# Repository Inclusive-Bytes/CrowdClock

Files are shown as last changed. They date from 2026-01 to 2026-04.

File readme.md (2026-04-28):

# CrowdClock

**Self-synchronising LED badges using ESP-NOW**

> A distributed system where devices don’t sync animations — they sync time.

---

## 🎥 Demo

See the badges in action:
👉 [https://youtu.be/YINVdLlnf9U(https://youtu.be/YINVdLlnf9U)

Badges automatically synchronise their lighting effects when they come close together.

* No pairing
* No configuration
* No central controller

They just… sync.

---

## 🧠 How It Works

Each badge broadcasts its local clock using ESP-NOW.
Instead of sending raw time, the value is **quantised into 50 ms steps**:

```cpp
tick = millis() - (millis() % 50);
```

When a badge receives a time value greater than its own, it adopts it:

```cpp
time = max(time_seen);
```

This creates a simple, emergent synchronisation mechanism:

* No master node
* No topology
* No device tracking

---

## 🔄 From Time to Light

All badges run the same code and derive their behaviour from time:

```
tick → effect index → effect state → LED output
```

* **Effect selection** is based on time
* **Effect state** is based on time

Once clocks align, everything else follows automatically.

---

## ⚙️ Why It Works

### 🔹 Quantised Time

Rounding time to 50 ms:

* Absorbs network latency
* Prevents oscillation
* Ensures stable convergence

### 🔹 Fast Broadcast

* ESP-NOW transmission every ~5 ms
* Multiple opportunities for propagation

### 🔹 Perceptual Design

Effects are:

* Flashes
* Chases
* Discrete patterns

This avoids visible artefacts from small timing differences.

---

## 🧩 Hardware

Each badge includes:

* ESP32-C3 Mini
* WS2812 LED ring
* 1Ah LiPo battery
* Boost/BMS module (5V output)

PCBs were CNC routed and assembled in workshops.

---

## 🔧 A Note on ESP32 Mounting

Early versions used socketed ESP32 modules.
This caused unreliable ESP-NOW reception.

Removing the sockets and soldering the modules directly resolved the issue.

At 2.4 GHz, small physical details matter.

---

## 👩‍🔧 Built with Inclusive Bytes

This project was developed with participants at
Inclusive Bytes

* Community workshops
* Soldering and assembly
* Custom lighting effects written by students

The system itself mirrors the process:

> many independent parts working together to create something unified.

---

## 🎉 In the Wild

The badges were created for the Oldham Illuminate Festival.

* Small groups synchronise
* Groups merge and re-align
* The crowd becomes part of the system

---

## 🚀 Future Ideas

* Visualising time propagation
* Multiple competing “time groups”
* Alternative effect systems
* Binary packet format (non-JSON)

---

## 📦 Repository Structure

https://github.com/Inclusive-Bytes/CrowdClock

```
/src            → firmware  
/include 		→ header files
/hardware       → PCB and design files  

```

---

## 📜 Licence

This project is released under a Creative Commons licence  CC BY-NC 4.0

You are free to:

* Share
* Adapt
* Build upon

Please provide appropriate credit.

---

## 💡 Key Idea

> Synchronise time, not state.

---

## 🙌 Acknowledgements

Thanks to everyone at Inclusive Bytes who helped build, test, and extend the badges.

---

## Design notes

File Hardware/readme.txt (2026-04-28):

All these files are produced with the free electronic cad package DesignSpark
https://uk.rs-online.com/web/content/services/manufacturing-design/rs-design-spark

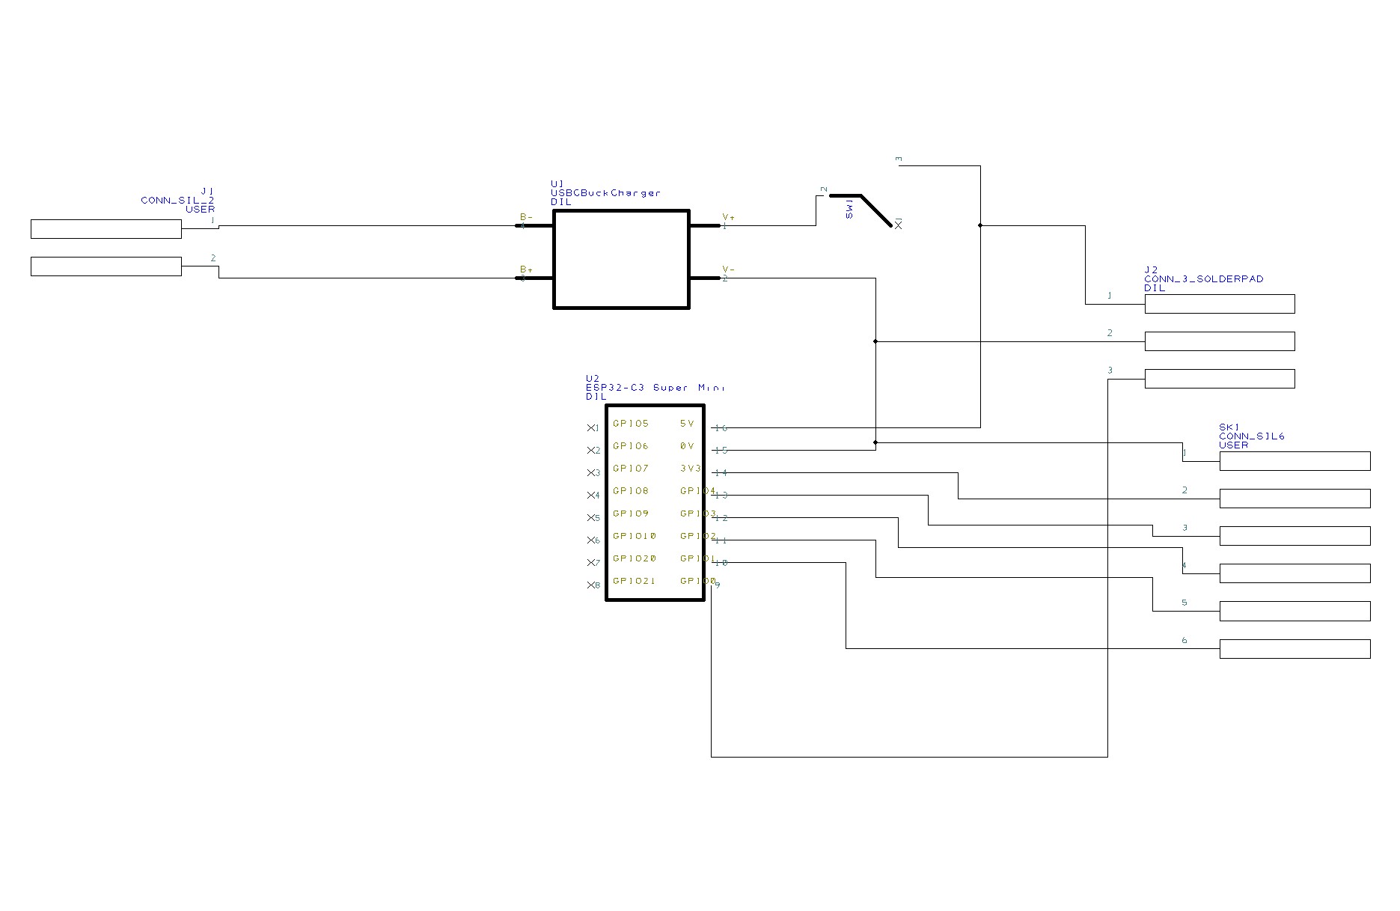
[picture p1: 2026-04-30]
Hardware/Schematic.jpg

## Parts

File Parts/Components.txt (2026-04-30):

Battery charger step up : https://www.aliexpress.com/item/1005005656423941.html
ESP32 C3: https://www.aliexpress.com/item/1005010195000050.html
WS2812 Ring. 16 LEDs: https://www.aliexpress.com/item/1005002304069758.html 
LipoBattery: https://www.aliexpress.com/item/1005010587681795.html
Slide switch: https://www.aliexpress.com/item/32797917204.html
Molex KK 2 way housing  254 : https://cpc.farnell.com/molex/10-11-2023/connector-rcpt-2pos-1row-2-54mm/dp/CN25601
Molex KK 2 way header 254: https://cpc.farnell.com/molex/22-27-2021/pin-header-0-1-2-way-lock/dp/CN09578
Molex KK crimps 254 x 2: https://cpc.farnell.com/molex/08-50-0113/contact-socket-22awg-crimp/dp/CN25571

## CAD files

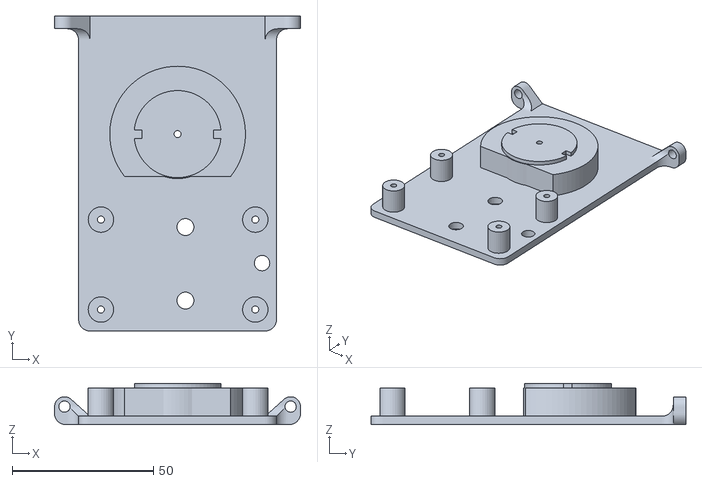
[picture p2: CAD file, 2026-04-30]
Parts/BadgeMount.stl
87.0 x 111.4 x 14.7

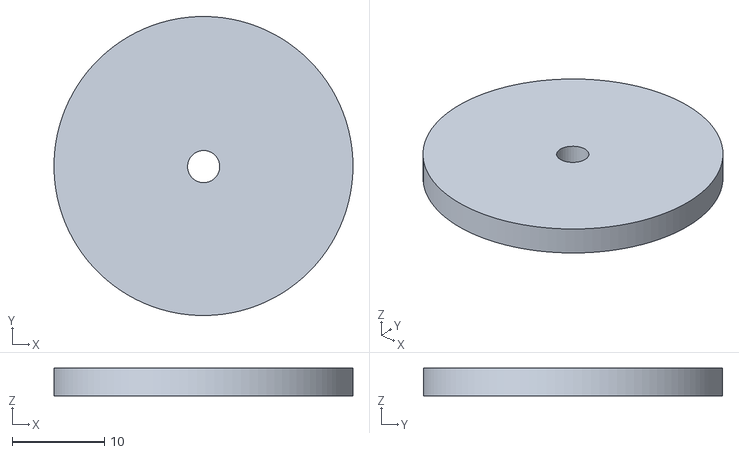
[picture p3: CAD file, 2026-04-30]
Parts/NeopixelClampRing.stl
32.5 x 32.5 x 3.00

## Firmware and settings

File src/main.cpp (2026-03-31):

/**
 * @file
 *
 * EspNowBroadcast.ino demonstrates how to perform ESP-NOW pseudo broadcast with @c WifiEspNowBroadcast .
 * You need two or more ESP8266 or ESP32 devices to run this example.
 *
 * All devices should run the same program.
 * You may need to modify the PIN numbers so that you can observe the effect.
 *
 * With the program running on several devices:
 * @li Press the button to transmit a message.
 * @li When a device receives a message, it will toggle its LED between "on" and "off" states.
 */

#include <WifiEspNowBroadcast.h>
#include "FastLED.h"
#if defined(ARDUINO_ARCH_ESP8266)
#include <ESP8266WiFi.h>
#elif defined(ARDUINO_ARCH_ESP32)
#include <WiFi.h>
#endif
#include "PacerLED.h"
#include "TxTime.h"
#include "JSONTime.h"
#include "TimeFilter.h"
#include "EffectManager.h"
#include "EffectStepColour.h"
#include "GenericFlasher.h"
#include "Ports.h"
#include "ContextStatusLed.h"
#include "EffectSwipe.h"
#include "EffectSynchronisedFlash.h"
#include "EffectHorizontalPath.h"
#include "EffectSpiral.h"
#include "EffectOrbit.h"
#include "EffectTriOrbit.h"


#define NUM_PIXELS 16

CRGB strip[NUM_PIXELS];



TxTime txTime(5, 5);  // Tx every 5ms scaled to 5ms

ContextStatusLed statusLED(STATUS_LED);

JSONTime jsonTime;
SystemTime systemTime;
TimeFilter timeFilter(&systemTime, 5);  // See if a new time received every 5ms

EffectManager effectManager;


GenericFlasher effectPurpleChase(CRGB(80,0,80), NUM_PIXELS);
GenericFlasher effectGreenChase(CRGB(0,128,0), NUM_PIXELS);
SwipeEffect   effectSwipe(CRGB(0,40,80), NUM_PIXELS);
SwipeEffect   effectSwipeRed(CRGB(200,0,0), NUM_PIXELS);
EffectSynchronisedFlash effectSyncFlash(NUM_PIXELS);
EffectHorizontalPath effectHorizontalPath(NUM_PIXELS, CRGB(20,0,180));
EffectSpiral effectSpiral(NUM_PIXELS);
EffectOrbit effectOrbitYellow(CRGB(127, 127, 0), NUM_PIXELS);
EffectOrbit effectOrbitGreen(CRGB(0, 255, 0), NUM_PIXELS);
EffectTriOrbit effectTriOrbitPurple(CRGB(127, 0, 127), NUM_PIXELS);
EffectTriOrbit effectTriOrbitCyan(CRGB(0, 127, 127), NUM_PIXELS);

void processRx(const uint8_t mac[WIFIESPNOW_ALEN], const uint8_t* buf, size_t count, void* arg)
{
  char message[count + 1] = {0};
  memcpy(message,buf, count);

  uint64_t rxTime = jsonTime.Update(message);
  if(rxTime != 0)
  {
    timeFilter.RxNewTime(rxTime);
  }
  statusLED.Kick();
}

void setup()
{
  Serial.begin(115200);
  delay(1000);
  Serial.println();

  FastLED.addLeds<NEOPIXEL   ,LED_PIN>(strip, NUM_PIXELS);

  WiFi.persistent(false);

  bool ok = WifiEspNowBroadcast.begin("ESPNOW", 3,3000);
  if (!ok) {
    Serial.println("WifiEspNowBroadcast.begin() failed");

    Pacer p(false);
    p.SetPace(2000);
    statusLED.SetPattern(0xaaaaaaaa,20);
    while(!p.Pace())
    {
      statusLED.Run();
    }
    ESP.restart();
 }
  Serial.println("Running");

  WifiEspNowBroadcast.onReceive(processRx, nullptr);



  Serial.print("MAC address of this node is ");
  Serial.println(WiFi.softAPmacAddress());

  effectManager.AddEffect(&effectPurpleChase);

  effectManager.AddEffect(&effectSwipe);
  effectManager.AddEffect(&effectGreenChase);
  effectManager.AddEffect(&effectOrbitYellow);
  effectManager.AddEffect(&effectTriOrbitCyan);
  effectManager.AddEffect(&effectSwipeRed);
  effectManager.AddEffect(&effectSyncFlash);
  effectManager.AddEffect(&effectHorizontalPath);
  effectManager.AddEffect(&effectSpiral);
  effectManager.AddEffect(&effectOrbitGreen);
  effectManager.AddEffect(&effectTriOrbitPurple);
}

void sendMessage(String& message)
{
 //Serial.println(message);
  WifiEspNowBroadcast.send(reinterpret_cast<const uint8_t*>(message.c_str()), message.length());

  //Serial.println("Sending message");
  //Serial.println(msg);
  /*
  Serial.print("Recipients:");
  const int MAX_PEERS = 20;
  WifiEspNowPeerInfo peers[MAX_PEERS];
  int nPeers = std::min(WifiEspNow.listPeers(peers, MAX_PEERS), MAX_PEERS);
  for (int i = 0; i < nPeers; ++i) {
    Serial.printf(" %02X:%02X:%02X:%02X:%02X:%02X", peers[i].mac[0], peers[i].mac[1],
                  peers[i].mac[2], peers[i].mac[3], peers[i].mac[4], peers[i].mac[5]);
  }
  Serial.println(); */
}


void loop()
{

  WifiEspNowBroadcast.loop();
  statusLED.Run();
  String sendTime = txTime.GetTxTimeAsString(&systemTime);
  if(sendTime.length())
  {
    sendMessage(sendTime);
  }
  timeFilter.Run();
  delay(2);
  effectManager.Run(strip, systemTime.GetTime());
  FastLED.show();
}

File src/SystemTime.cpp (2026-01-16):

#include "SystemTime.h"



SystemTime::SystemTime()
{
    m_currentOffset = 0; 
}

void SystemTime::UpdateTime(uint64_t newTime)
{
    Serial.print(" New time is");
    Serial.print(newTime);
    Serial.print(" Local time is " );
  
    uint64_t now =GetTime();
      Serial.println(now);
    if(newTime > now)
    {
        m_currentOffset = m_currentOffset + (newTime - now);
        Serial.print("Changing offset to ");
        Serial.println(m_currentOffset);
    }  
   
    Serial.print("New system time is ");
    Serial.println(GetTime());
}

uint64_t SystemTime::GetTime()
{
    uint64_t now = millis() + m_currentOffset;
    return  now - (now % 50);
}

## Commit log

2026-01-15 Sends timer data every 10ms
2026-01-15 System time filter now working
2026-01-15 First check in of adding LEDs
2026-01-15 LED sync working. Needs tidying up
2026-01-16 LEDs now synch OK. Code tidied
2026-01-17 Context LED done
2026-01-18 Added hardware folder
    [LightNightBadge.sch, ~LightNightBadge.sch]
2026-01-25 Moved switch down on PCB to clear ESP. Made RGB leds connector into solder pads
    [LightNightBadge.sch, ~LightNightBadge.sch]
2026-04-28 Added plots and readme
    [LightNightBadge - Bottom Copper.gbr, LightNightBadge - Bottom Silkscreen.gbr, LightNightBadge - Bottom Solder Mask.gbr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]
2026-04-30 Added badge parts
    [BadgeMount.stl, NeopixelClampRing.stl]
2026-04-30 Added schematic.jpg
